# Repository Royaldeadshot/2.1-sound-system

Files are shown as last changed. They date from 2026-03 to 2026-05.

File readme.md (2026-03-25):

# DIY 3-Way Speaker Crossover + Amplifier System

This project is a custom-built 3-way audio system designed from scratch, including the amplifier, crossover network, and speaker configuration. The goal was to create a solid, practical setup that delivers good sound without overcomplicating the design.

---

## 🔊 System Overview

- Subwoofer: 10" DVC (handles low frequencies)
- Tower Speakers (x2):
  - 2 × Woofers (connected in series → 8Ω)
  - 1 × Midrange driver (4Ω)
  - 1 × Tweeter (4Ω)

- Passive 3-way crossover (2nd order)
- Custom PCB amplifier
  - Dual TPA3255 based amplifier

---

## 📸 Screenshots

### Full Build
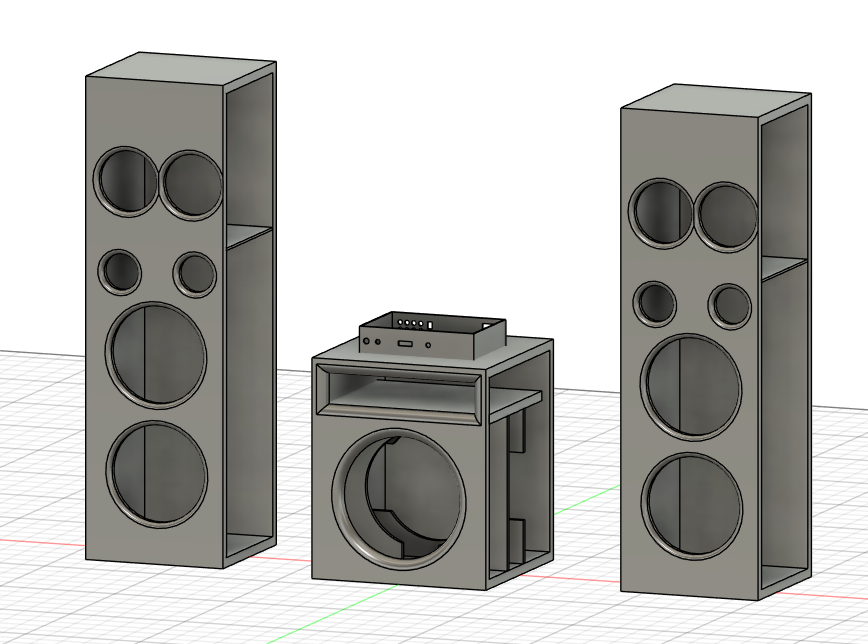
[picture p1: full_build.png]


### PCB Layout
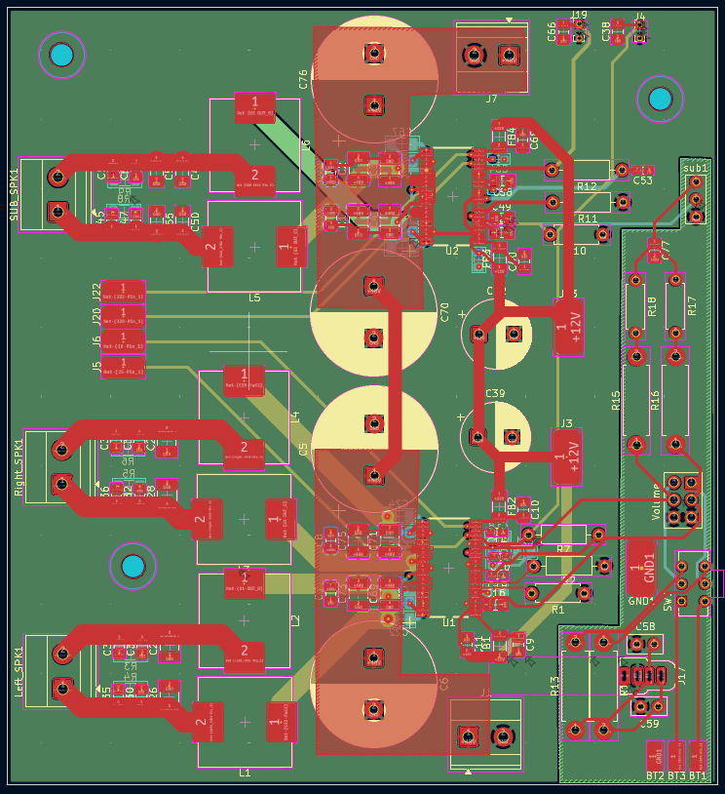
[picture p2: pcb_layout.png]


---

### Schematic
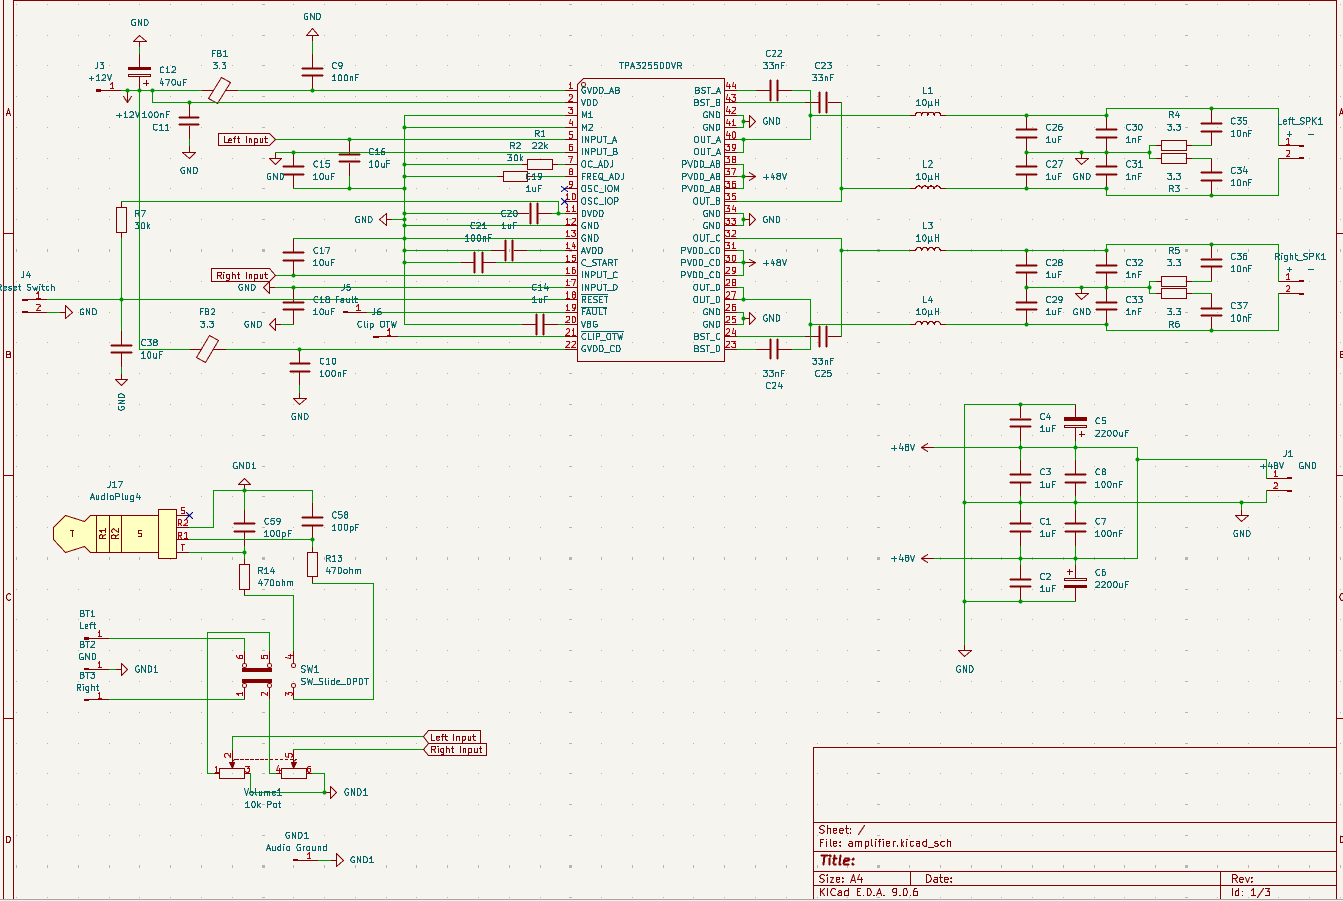
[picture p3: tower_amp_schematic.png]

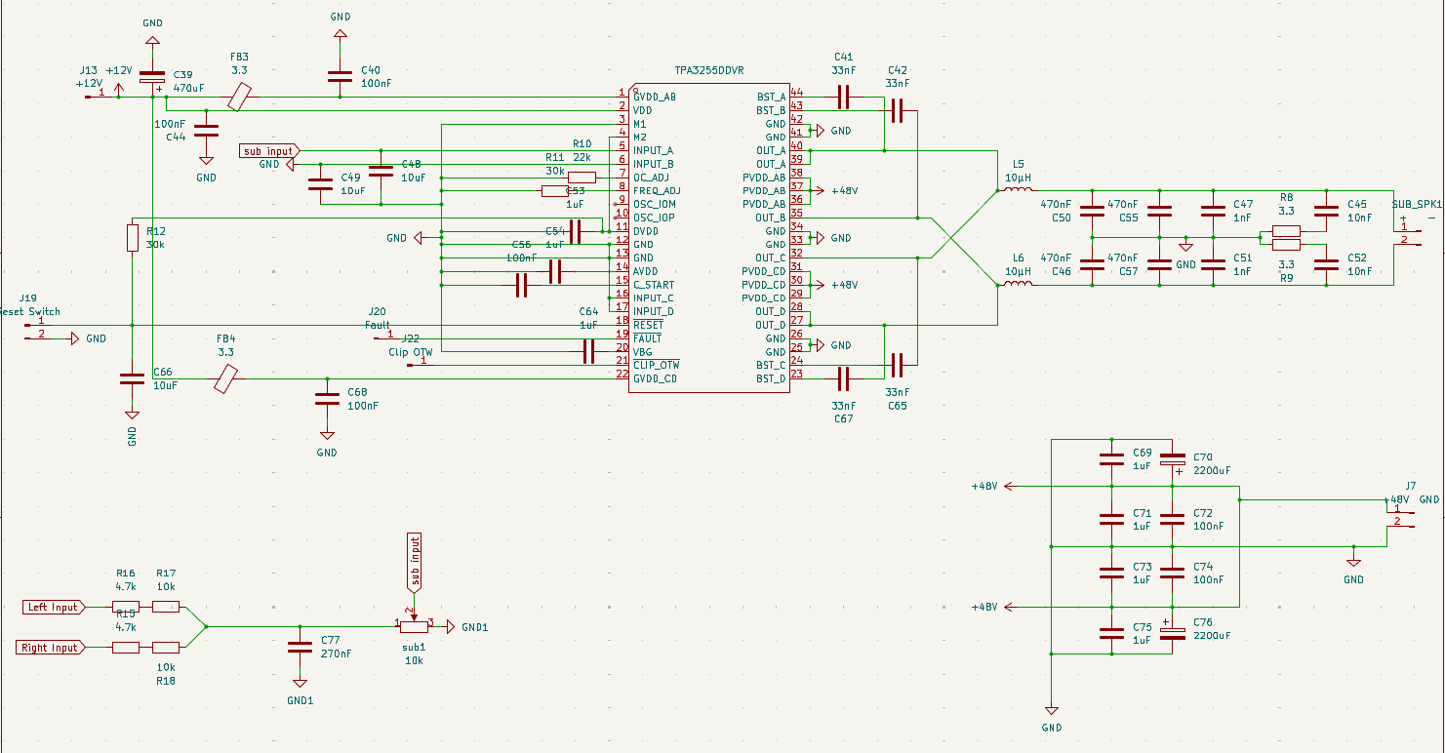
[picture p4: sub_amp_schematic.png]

---

### 3D Model
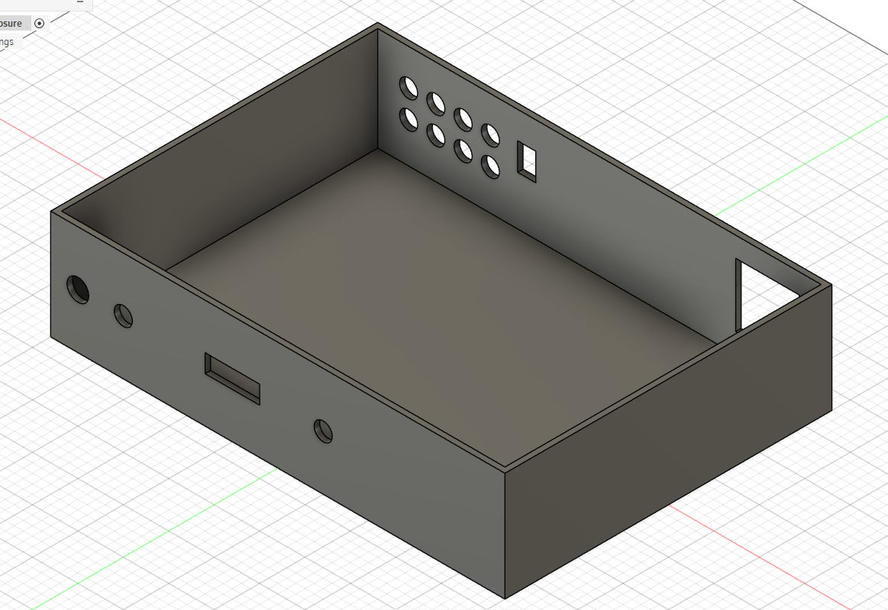
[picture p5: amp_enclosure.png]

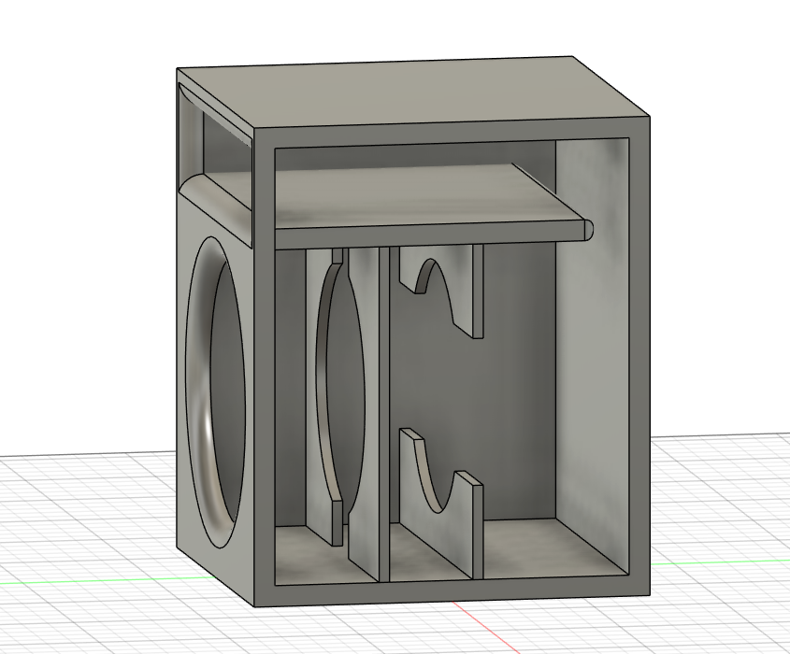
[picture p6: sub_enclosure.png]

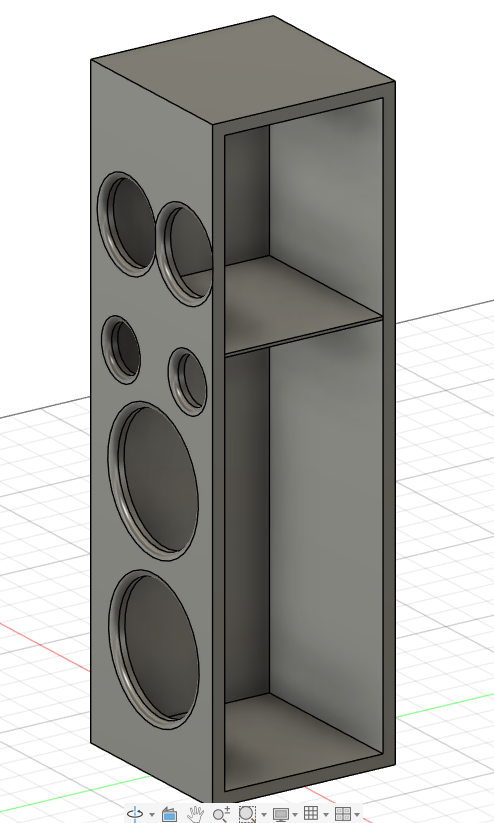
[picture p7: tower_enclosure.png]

---

### Crossover Design
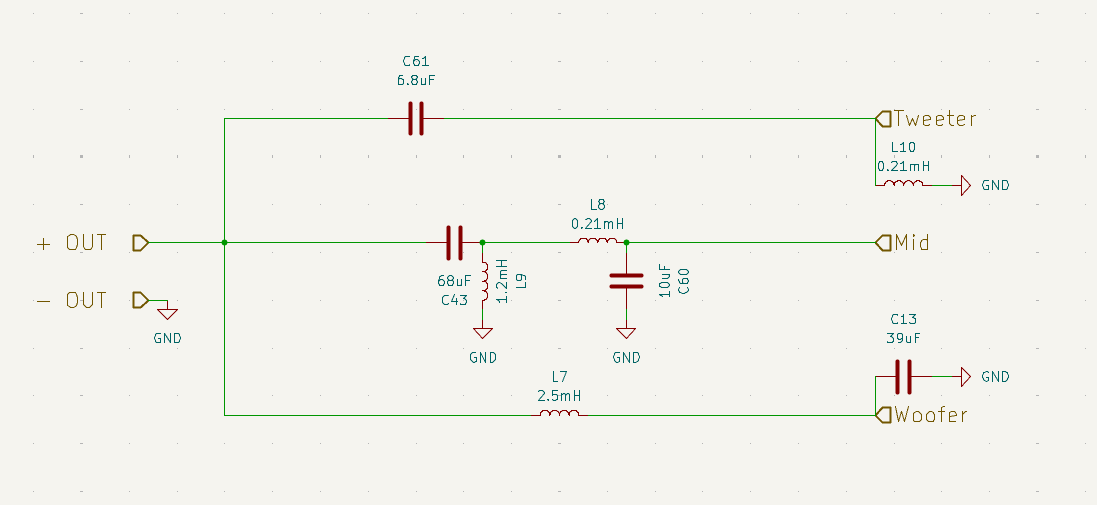
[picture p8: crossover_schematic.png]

---

## ⚙️ How It Works (Short)

The Power supply power up the sytem and then 48V and 12V are sent to amp power pins, and then 12v is also used to power up the fans for cooling the HOT TPA3255 chips, then the 5v is sent to bt module

after that we select aux or bt input through the dpdt switch, and the signal goes to the tower amp and a 80hz cutoff is sent to the sub amp, the amp amplify the dignal and then the amplifier sends a full-range audio signal to the crossover in tower speaker and the cutoff freq to sub.

The crossover splits this signal into three parts:

- Low frequencies → go to the woofers  
- Mid frequencies → go to the mid driver  
- High frequencies → go to the tweeter  

This is done using inductors and capacitors arranged as filters:

- Inductors block high frequencies  
- Capacitors block low frequencies  

Each driver only receives the frequencies it is meant to play, improving clarity and reducing distortion.

---

## 🧠 Design Choices

- TPA3255 for 250 watt per channel and 300-600 Watt for sub
- Used a 2nd order crossover (12dB/octave) for better separation   
- used a active crossover for sub to save cost

---

## 🧾 Components Used

BOM list present in the bom.csv in this repo root directory

---

## 🚀 Status

- [x] Amplifier designed  
- [x] PCB layout completed  
- [x] Crossover designed
- [X] Input Stage made
- [X] SUB frequecny cutoff of 80hz made
- [X] Tuned Enclosure design made
- [X] Drivers selected
- [X] BOM made
- [ ] Assembly  
- [ ] Testing  

---

## 📌 Future Improvements

- Fine-tune crossover after listening tests  
- Improve enclosure design  
- Add damping and internal bracing  

---

This is a work-in-progress build focused on learning and practical implementation rather than perfection.

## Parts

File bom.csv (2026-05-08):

S. No. | PCB Annotations | Part Name | Qty. | Unit Price(?) | Total Price(?) | Product link | Total Cost in $
1 | U1,U2 | TPA3255DDVR | 2 | 396 | 807 | https://www.lcsc.com/product-detail/C468240.html?s_z=n_tpa3255 | 8.54
2 | L1-L6 | 10uH Inductor | 7 | 32.5 | 276.6 | https://www.lcsc.com/product-detail/C5349630.html | 2.92
3 | SW1 | DPDT switch | 1 | 4.57 | 4.57 | https://robu.in/product/sk-3245d-02-l4-xkb-50ma-dpdt-12v-12v-50ma-10000-times-black-plugin-slide-switches-rohs/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 | 0.04
4 | J17 | aux input jack | 1 | 2.75 | 2.75 | https://robu.in/product/smartelex-audio-jack-3-5mm-trrs-smd/ | 0.02
5 | C77 | 270nF Ceramic Capacitor X7R 50V | 2 | 0.6 | 1.2 | https://robu.in/product/tcc0805x7r274k500dt-cctc-smt-ceramic-capacitors-0805-x7r-274k270nf%c2%b110-rated-voltage50v-thickness0-85mmtape/ | 0.01
6 | C59,C58 | 100pF ceramic capacitor 50V | 3 | 0.71 | 2.13 | https://robu.in/product/100pf-50v-ceramic-capacitordip-pack-of-50/ | 0.02
7 | R13,R14 | 470ohm resistor | 3 | 1 | 3 | https://robu.in/product/470-ohm-0-5w-metal-film-resistor-pack-of-50/ | 0.03
8 | J18 | Bluetooth Module | 1 | 300 | 300 | https://robocraze.com/products/dfrobot-bluetooth-5-0-audio-receiver-board?_pos=2&_sid=4add056a5&_ss=r | 3.17
9 | SUB1 | 10k Potentiometer A taper | 1 | 18 | 18 | https://makerbazar.in/products/wh148-3pin-20mm-rotary-shaft-potentiometer-audio-logarithm-a-taper-pots | 0.19
10 | VOLUME1 | 10k Potentiometer Dual gang | 1 | 22 | 22 | https://robu.in/product/10k%cf%89-0-2w-6-pin-2-gang-rotary-carbon-potentiometer-15mm/ | 0.23
11 | R15,R16 | 4.7k ohm metal film resistor | 3 | 0.7 | 2.1 | https://robu.in/product/4-7k-ohm-0-5w-metal-film-resistor-pack-of-50/ | 0.02
12 | R17,R18 | 10k ohm metal film resistor | 3 | 0.35 | 1.05 | https://robu.in/product/10k-ohm-0-25w-metal-film-resistor-pack-of-100/ | 0.01
13 | C1-4,C26-29,C69,C71,C73,C75 | 1uF Capacitor 100V ceramic | 15 | 9 | 135 | https://robu.in/product/cl32b105kcjnnne-samsang-100v-1uf-x7r-%c2%b110-1210-multilayer-ceramic-capacitors-mlcc-smd-smt-rohs/ | 1.43
14 | C53,C54,C64,C19,C20,C14 | 1uF Capacitor 25V ceramic | 8 | 1.61 | 12.88 | https://robu.in/product/tmk107b7105ka-t-taiyo-yuden-mlcc-capacitor-1uf-25v-x7r-10-0603/ | 0.14
15 | C5-6,C70,C76 | 2200uF electrolytic capacitor 63V | 5 | 141 | 705 | https://robu.in/product/upw1j222mhd-nichicon-2200uf-63v-%c2%b120-plugind18xl40mm-aluminum-electrolytic-capacitors-leaded-rohs/ | 7.46
16 | C40,C44,C68,C56,C72,C74,C9-11,C21,C7-8 | 100nF ceramic capacitor | 15 | 2.44 | 36.6 | https://robu.in/product/gcj21br72a104ka01l-murata-electronics-100v-100nf-x7r-%c2%b110-0805-multilayer-ceramic-capacitors-mlcc-smd-smt-rohs/ | 0.38
17 | C12,C39 | 470uF Electrolytic capacitor 50V | 3 | 7 | 21 | https://robu.in/product/470uf-50v-through-hole-1020-electrolytic-capacitor-pack-of-250/ | 0.22
18 | C15-18,C38,C48,C49,C66 | 10uF Ceramic Capacitor | 10 | 3.17 | 31.7 | https://robu.in/product/10uf-10000nf-25-v-capacitor-0805-smd-package-pack-of-10/ | 0.33
19 | C22-25,C41,C42,C65,C67 | 33nF 100V Ceramic Capacitor X7R | 10 | 0.79 | 7.9 | https://robu.in/product/tcc1206x7r333k101dt-cctc-smt-ceramic-capacitors-1206-x7r-333k33nf%c2%b110-rated-voltage100v-thickness0-85mm-tape/ | 0.08
20 | R1,R10 | 22k Ohm 0.25W Metal Film Resistor | 4 | 0.25 | 1 | https://robu.in/product/22k-ohm-0-25w-metal-film-resistor-pack-of-100/ | 0.01
21 | R2,R7,R11,R12 | 30k Ohm metal film Resistor | 5 | 2.18 | 10.9 | https://robu.in/product/mf25-30k-multicomp-pro-through-hole-resistor-30-kohm-mf25-series-250-mw-%c2%b1-1-axial-leaded-250-v/ | 0.11
22 | FB1-4, R3-R6,R8,R9 | 3.3Ohm Thick Filmc Resistor SMD | 15 | 0.26 | 3.9 | https://robu.in/product/1206w4f330kt5e-uniohm-royal-ohm-250mw-thick-film-resistors-200v-%c2%b11-%c2%b1400ppm-%e2%84%83-3-3%cf%89-1206-chip-resistor-surface-mo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 | 0.04
23 | C30-C33, C47, C51 | 1nF Capacitor 100V | 10 | 1.01 | 10.1 | https://robu.in/product/cc0805krx7r0bb102-yageo-100v-1nf-x7r-%c2%b110-0805-multilayer-ceramic-capacitors-mlcc-smd-smt-rohs/ | 0.1
24 | C34-C37, C45, C52 | 10nF Capacitor 100V | 10 | 1.79 | 17.9 | https://robu.in/product/gcm21br72a103ka37l-murata-electronics-100v-10nf-x7r-%c2%b110-0805-multilayer-ceramic-capacitors-mlcc-smd-smt-rohs/ | 0.18
25 | C46, C50, C55, C57 | 470nF Capacitor 100V | 6 | 1.73 | 10.38 | https://robu.in/product/1206b474k101nt-fh-100v-470nf-x7r%c2%b110-1206-multilayer-ceramic-capacitors-mlcc-smd-smt-rohs/ | 0.11
26 |  | Screw Terminal | 8 | 13 | 104 | https://robu.in/product/xy104-5-0-xinya-2-pin-screw-terminal-blockblue/ | 1.1
27 |  | 4mm Banana Plug Socket | 8 | 13 | 104 | https://robu.in/product/4mm-banana-socket-binding-post-nut-banana-plug-jack-connector/ | 1.1
28 |  | 48V To 12V Converter | 1 | 128 | 128 | https://robu.in/product/dc13-100v-to-12v-2a-buck-power-conversion-module/ | 1.35
29 |  | 40mm Fan | 2 | 65 | 130 | https://makerbazar.in/products/generic-axial-dc-cooling-fan-blowers?variant=46306240004336 | 1.37
30 |  | Aluminium Heat Sink 9 x 9 x 12 mm | 4 | 29 | 116 | https://robocraze.com/products/aluminum-cooling-heat-sink-chip-ram-radiator-heatsink-cooler-reprap-stepstick-heat-sink-9x9x12mm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 | 1.22
31 |  | 12V to 5V Converter | 1 | 166 | 166 | https://robu.in/product/24v-12v-to-5v-5a-power-module-dc-dc-xy-3606-power-converter/ | 1.75
32 |  | Heat Shrink Sleeve 8mm | 2 | 9 | 18 | https://robu.in/product/heat-shrink-sleeve-8mm-black-industrial-grade-woer-hst/ | 0.19
33 |  | 48V Power Supply 1000 Watts | 1 | 6999 | 6999 | https://www.amazon.in/Switching-Universal-Regulated-Transformer-1000Watts/dp/B0DNZJBZRN | 74.08
34 |  | 39uF Capacitor for Crossover | 2 | 13 | 26 | https://robu.in/product/100yxg39mefc8x16-rubycon-39uf-100v-%c2%b120-plugind8xl16mm-aluminum-electrolytic-capacitors-leaded-rohs/ | 0.27
35 |  | 68uF Capacitor for Crossover | 2 | 18 | 36 | https://robu.in/product/uhe2a680mpd1td-nichicon-68uf-%c2%b120-plugind10xl16mm-aluminum-electrolytic-capacitors-leaded-rohs/ | 0.38
36 |  | 2.5mH 16 AWG Steel Laminate Inductors | 2 | 700 | 1400 | https://audiofy.in/collections/air-core-coils/products/audiofy-2-5mh-16-awg-steel-laminate-inductors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 | 14.81
37 |  | 1.2mH 16 AWG Air Core Crossover Inductor | 2 | 960 | 1920 | https://audiofy.in/collections/air-core-coils/products/audiofy-1-2mh-16-awg-air-core-crossover-inductor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 | 20.32
38 |  | 0.21mH 16 AWG Air Core Crossover Inductor | 4 | 400 | 1600 | https://audiofy.in/products/audiofy-0-21mh-16-awg-air-core-crossover-inductor?_pos=3&_fid=0ef5b0c1e&_ss=c | 16.93
39 |  | 6.8uF 400VDC Metalized Polypropylene Capacitor | 2 | 190 | 380 | https://audiofy.in/collections/capacitors/products/audiofy-6-8uf-400vdc-metalized-polypropylene-capacitor | 4.02
40 |  | 10uF 400VDC Metalized Polypropylene Capacitor | 2 | 250 | 500 | https://audiofy.in/collections/capacitors/products/audiofy-10uf-400vdc-metalized-polypropylene-capacitor | 5.29
 |  | 16AWG black wire | 4 | 48 | 192 | https://robu.in/product/16awg-high-voltage-silicone-wire-3000v-black/ | 2.03
 |  | 16AWG red wire | 4 | 48 | 192 | https://robu.in/product/16awg-high-voltage-silicone-wire-3000v-red/ | 2.03
 |  | Multicore wire 14AWG | 2 | 202 | 404 | https://robu.in/product/14awg-multicore-insulated-cable2-cores-silicone/ | 4.28
 |  | 24AWG wire black | 1 | 12 | 12 | https://robu.in/product/24awg-high-voltage-silicone-wire-3000v-black/ | 0.12
 |  | 24AWG wire red | 1 | 12 | 12 | https://robu.in/product/24awg-high-voltage-silicone-wire-3000v-red/ | 0.12

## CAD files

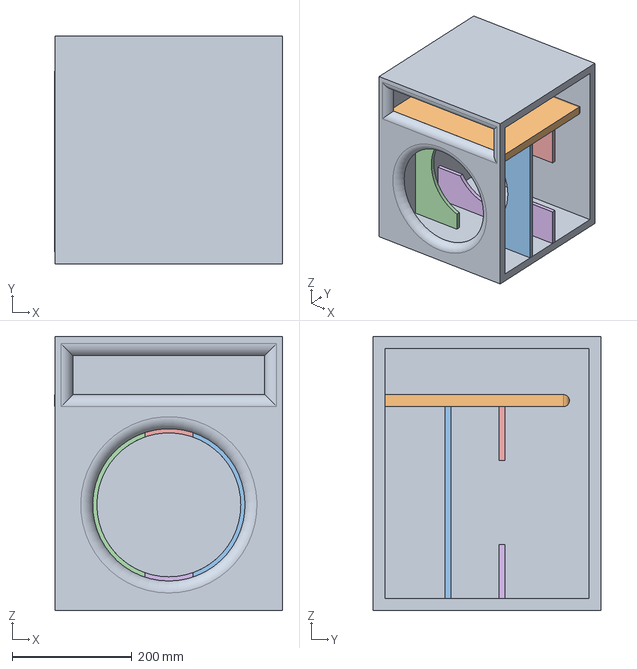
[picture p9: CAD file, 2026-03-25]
CAD/Sub Woofer Enclosure.step
381.0 x 380.0 x 457.0 mm

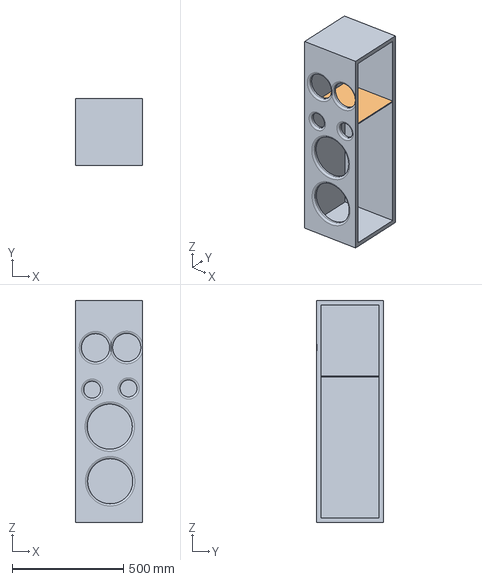
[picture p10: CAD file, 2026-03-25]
CAD/Tower Design.step
300.0 x 300.0 x 1000.0 mm

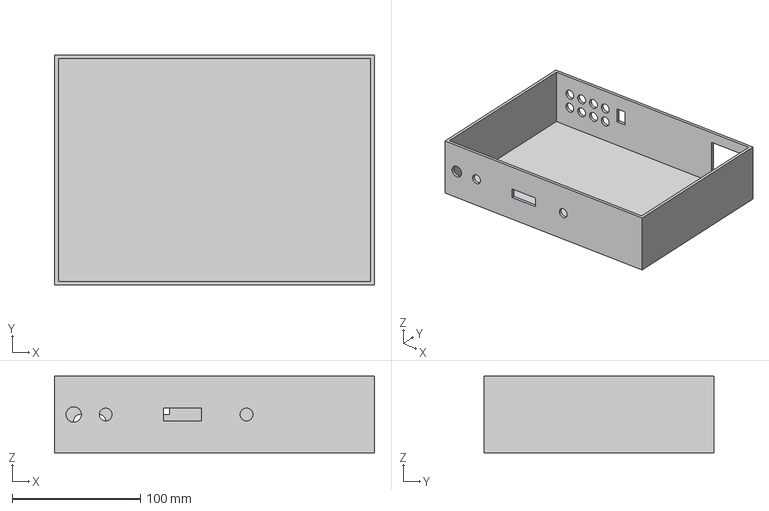
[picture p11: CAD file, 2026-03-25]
CAD/Amplifier Enclosure.step
250.0 x 180.0 x 60.0 mm

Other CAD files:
CAD/Amplifier Enclosure.f3d
CAD/Sub Woofer Enclosure.f3d
CAD/Tower Design.f3d

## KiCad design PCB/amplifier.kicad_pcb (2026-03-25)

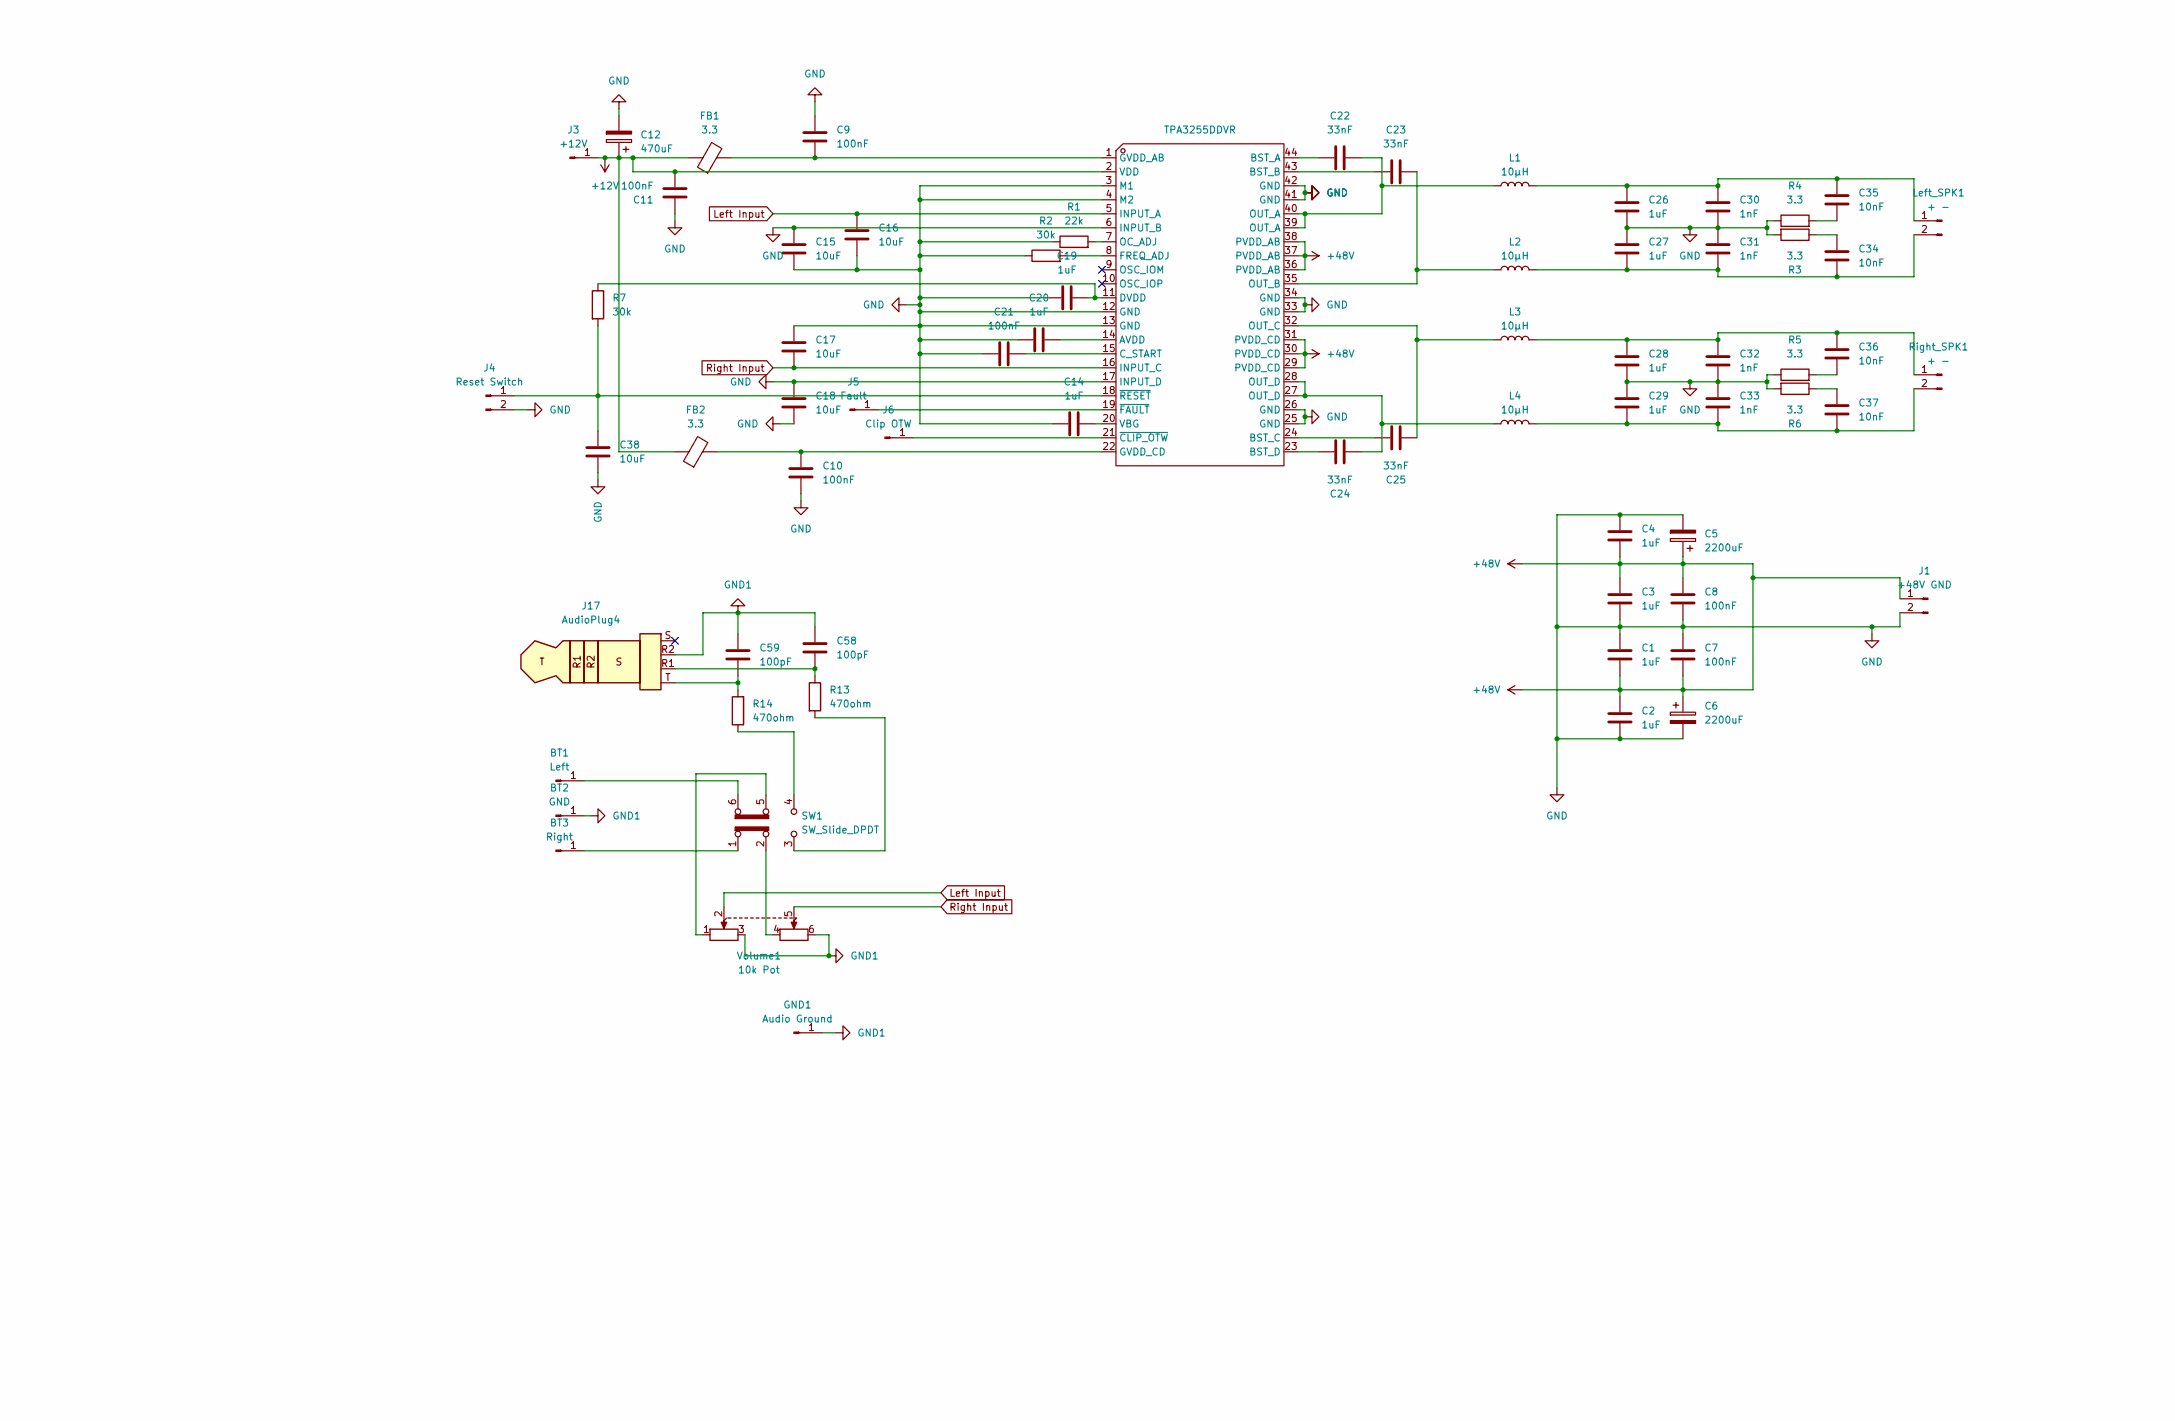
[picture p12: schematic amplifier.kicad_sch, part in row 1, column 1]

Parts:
BT1: Left; SolderWirePad_1x01_SMD_2x4mm
BT2: GND; SolderWirePad_1x01_SMD_2x4mm
BT3: Right; SolderWirePad_1x01_SMD_2x4mm
C1, C2, C3, C4, C26, C27, C28, C29: 1uF; C_1210_3225Metric_Pad1.33x2.70mm_HandSolder
C5, C6: 2200uF; CP_Radial_D18.0mm_P7.50mm
C7, C8, C9, C10, C11, C21: 100nF; C_0805_2012Metric_Pad1.18x1.45mm_HandSolder
C12: 470uF; CP_Radial_D10.0mm_P5.00mm
C14, C19, C20: 1uF; C_0603_1608Metric_Pad1.08x0.95mm_HandSolder
C15, C16, C17, C18, C38: 10uF; C_0805_2012Metric_Pad1.18x1.45mm_HandSolder
C22, C23, C24, C25: 33nF; C_1206_3216Metric_Pad1.33x1.80mm_HandSolder
C30, C31, C32, C33: 1nF; C_0805_2012Metric_Pad1.18x1.45mm_HandSolder
C34, C35, C36, C37: 10nF; C_0805_2012Metric_Pad1.18x1.45mm_HandSolder
C58, C59: 100pF; C_Disc_D5.0mm_W2.5mm_P2.50mm
FB1, FB2: 3.3; R_1206_3216Metric_Pad1.30x1.75mm_HandSolder
GND1: Audio Ground; SolderWirePad_1x01_SMD_4x8mm
J1: +48V GND; TerminalBlock_Phoenix_MKDS-1,5-2_1x02_P5.00mm_Horizontal
J3: +12V; SolderWirePad_1x01_SMD_4x8mm
J4: Reset Switch; PinHeader_1x02_P1.00mm_Vertical
J5: Fault; SolderWirePad_1x01_SMD_3x6mm
J6: Clip OTW; SolderWirePad_1x01_SMD_3x6mm
J17: AudioPlug4; Plug_3.5mm_CUI_SP-3541
L1, L2, L3, L4: 10µH; L_APV_APH1265
Left_SPK1: + -; TerminalBlock_Phoenix_MKDS-1,5-2_1x02_P5.00mm_Horizontal
R1: 22k; R_Axial_DIN0207_L6.3mm_D2.5mm_P7.62mm_Horizontal
R2, R7: 30k; R_Axial_DIN0207_L6.3mm_D2.5mm_P10.16mm_Horizontal
R3, R4, R5, R6: 3.3; R_1206_3216Metric_Pad1.30x1.75mm_HandSolder
R13, R14: 470ohm; R_Axial_DIN0411_L9.9mm_D3.6mm_P12.70mm_Horizontal
Right_SPK1: + -; TerminalBlock_Phoenix_MKDS-1,5-2_1x02_P5.00mm_Horizontal
SW1: SW_Slide_DPDT; SW_CK_JS202011AQN_DPDT_Angled
U1: TPA3255DDVR; HTSSOP-44_L14.0-W6.1-P0.64-LS8.1-BL; LCSC Part C468240
Volume1: 10k Pot; Potentiometer_Alpha_RD902F-40-00D_Dual_Vertical

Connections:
+12V: C11.2, C12.1, FB1.1, FB2.1, J3.1, U1.2 (VDD); also elsewhere on the board
+48V: C1.2, C2.1, C3.1, C4.2, C5.1, C6.1, C7.2, C8.1, J1.1, U1.29 (PVDD_CD), U1.30 (PVDD_CD), U1.31 (PVDD_CD), U1.36 (PVDD_AB), U1.37 (PVDD_AB), U1.38 (PVDD_AB); also elsewhere on the board
GND: C1.1, C2.2, C3.2, C4.1, C5.2, C6.2, C7.1, C8.2, C9.2, C10.1, C11.1, C12.2, C14.2, C15.1, C15.2, C16.2, C17.1, C18.1, C18.2, C19.1, C20.1, C21.1, C26.2, C27.1, C28.2, C29.1, C30.2, C31.1, C32.2, C33.1, C38.1, J1.2, J4.2, R1.1, R2.1, R3.2, R4.1, R5.1, R6.2, U1.3 (M1), U1.4 (M2), U1.6 (INPUT_B), U1.12 (GND), U1.13 (GND), U1.17 (INPUT_D), U1.25 (GND), U1.26 (GND), U1.33 (GND), U1.34 (GND), U1.41 (GND), U1.42 (GND); also elsewhere on the board
GND1: BT2.1, C58.1, C59.2, GND1.1, J17.R2, Volume1.3, Volume1.6; also elsewhere on the board
Left Input: C16.1, U1.5 (INPUT_A), Volume1.2; also elsewhere on the board
unnamed: BT1.1, SW1.6 (C)
unnamed: BT3.1, SW1.1 (A)
unnamed: C22.2, L1.1, U1.39 (OUT_A), U1.40 (OUT_A)
unnamed: C24.1, L4.1, U1.27 (OUT_D), U1.28 (OUT_D)
unnamed: C34.1, R3.1
unnamed: C35.2, R4.2
unnamed: C36.2, R5.2
unnamed: C37.1, R6.1
unnamed: C58.2, J17.R1, R13.1
unnamed: C59.1, J17.T, R14.2
unnamed: C38.2, J4.1, R7.2, U1.18 (~RESET)
unnamed: J5.1, U1.19 (~FAULT)
unnamed: J6.1, U1.21 (~CLIP_OTW)
unnamed: C26.1, C30.1, C35.1, L1.2, Left_SPK1.1
unnamed: C27.2, C31.2, C34.2, L2.2, Left_SPK1.2
unnamed: R13.2, SW1.3 (C)
unnamed: R14.1, SW1.4 (A)
unnamed: C28.1, C32.1, C36.1, L3.2, Right_SPK1.1
unnamed: C29.2, C33.2, C37.2, L4.2, Right_SPK1.2
unnamed: SW1.2 (B), Volume1.4
unnamed: SW1.5 (B), Volume1.1
unnamed: C20.2, U1.14 (AVDD)
unnamed: C22.1, U1.44 (BST_A)
unnamed: C23.1, U1.43 (BST_B)
unnamed: C25.2, U1.24 (BST_C)
unnamed: C24.2, U1.23 (BST_D)
unnamed: C21.2, U1.15 (C_START)
unnamed: C19.2, R7.1, U1.11 (DVDD)
unnamed: R2.2, U1.8 (FREQ_ADJ)
unnamed: C9.1, FB1.2, U1.1 (GVDD_AB)
unnamed: C10.2, FB2.2, U1.22 (GVDD_CD)
unnamed: R1.2, U1.7 (OC_ADJ)
unnamed: C23.2, L2.1, U1.35 (OUT_B)
unnamed: C25.1, L3.1, U1.32 (OUT_C)
unnamed: C14.1, U1.20 (VBG)
Right Input: C17.2, U1.16 (INPUT_C), Volume1.5; also elsewhere on the board

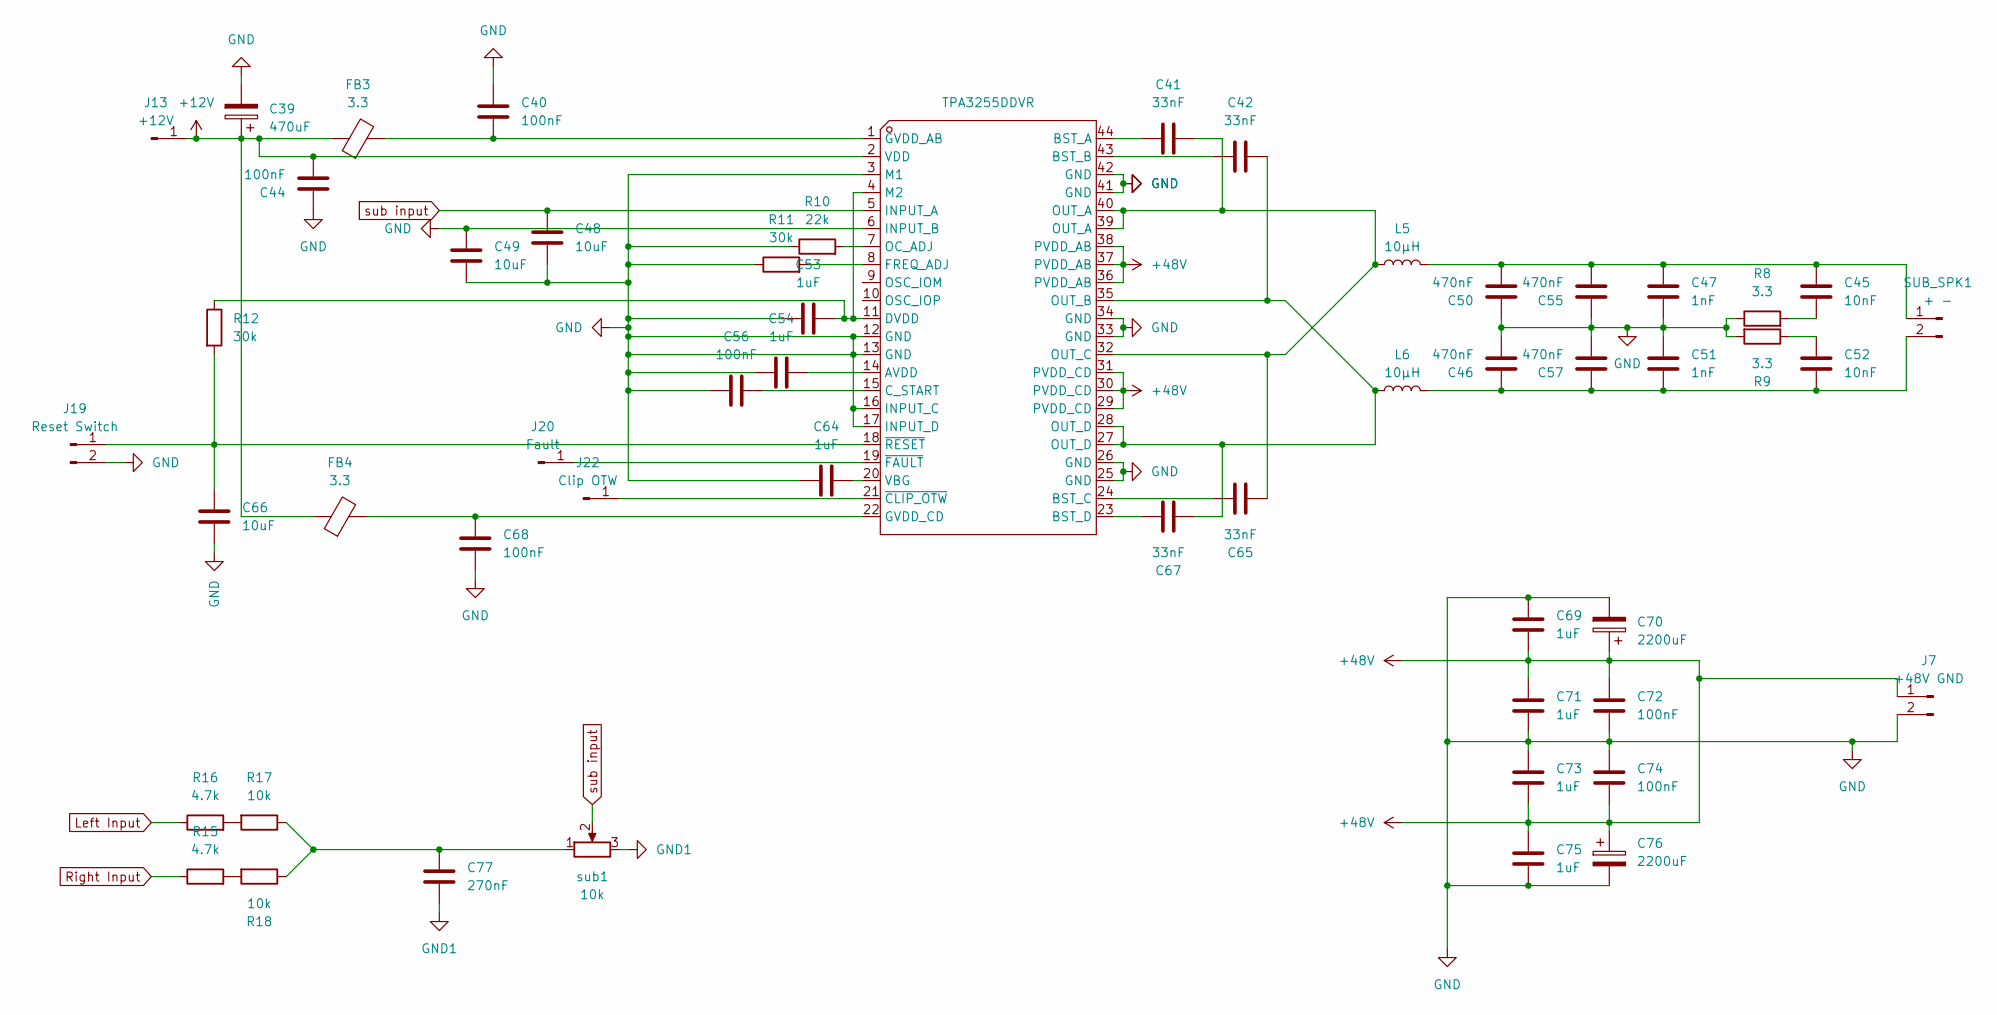
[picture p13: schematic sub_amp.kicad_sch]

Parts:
C39: 470uF; CP_Radial_D10.0mm_P5.00mm
C40, C44, C56, C68, C72, C74: 100nF; C_0805_2012Metric_Pad1.18x1.45mm_HandSolder
C41, C42, C65, C67: 33nF; C_1206_3216Metric_Pad1.33x1.80mm_HandSolder
C45, C52: 10nF; C_0805_2012Metric_Pad1.18x1.45mm_HandSolder
C46, C50, C55, C57: 470nF; C_1206_3216Metric_Pad1.33x1.80mm_HandSolder
C47, C51: 1nF; C_0805_2012Metric_Pad1.18x1.45mm_HandSolder
C48, C49, C66: 10uF; C_0805_2012Metric_Pad1.18x1.45mm_HandSolder
C53, C54, C64: 1uF; C_0603_1608Metric_Pad1.08x0.95mm_HandSolder
C69, C71, C73, C75: 1uF; C_1210_3225Metric_Pad1.33x2.70mm_HandSolder
C70, C76: 2200uF; CP_Radial_D18.0mm_P7.50mm
C77: 270nF; C_0805_2012Metric_Pad1.18x1.45mm_HandSolder
FB3, FB4: 3.3; R_1206_3216Metric_Pad1.30x1.75mm_HandSolder
J7: +48V GND; TerminalBlock_Phoenix_MKDS-1,5-2_1x02_P5.00mm_Horizontal
J13: +12V; SolderWirePad_1x01_SMD_4x8mm
J19: Reset Switch; PinHeader_1x02_P1.00mm_Vertical
J20: Fault; SolderWirePad_1x01_SMD_3x6mm
J22: Clip OTW; SolderWirePad_1x01_SMD_3x6mm
L5, L6: 10µH; L_APV_APH1265
R8, R9: 3.3; R_1206_3216Metric_Pad1.30x1.75mm_HandSolder
R10: 22k; R_Axial_DIN0207_L6.3mm_D2.5mm_P7.62mm_Horizontal
R11, R12: 30k; R_Axial_DIN0207_L6.3mm_D2.5mm_P10.16mm_Horizontal
R15, R16: 4.7k; R_Axial_DIN0411_L9.9mm_D3.6mm_P12.70mm_Horizontal
R17, R18: 10k; R_Axial_DIN0207_L6.3mm_D2.5mm_P7.62mm_Horizontal
SUB_SPK1: + -; TerminalBlock_Phoenix_MKDS-1,5-2_1x02_P5.00mm_Horizontal
U2: TPA3255DDVR; HTSSOP-44_L14.0-W6.1-P0.64-LS8.1-BL; LCSC Part C468240
sub1: 10k; Potentiometer_ACP_CA6-H2,5_Horizontal

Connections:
+12V: C39.1, C44.2, FB3.1, FB4.1, J13.1, U2.2 (VDD); also elsewhere on the board
+48V: C69.2, C70.1, C71.1, C72.1, C73.2, C74.2, C75.1, C76.1, J7.1, U2.29 (PVDD_CD), U2.30 (PVDD_CD), U2.31 (PVDD_CD), U2.36 (PVDD_AB), U2.37 (PVDD_AB), U2.38 (PVDD_AB); also elsewhere on the board
GND: C39.2, C40.2, C44.1, C46.2, C47.2, C48.2, C49.1, C49.2, C50.1, C51.1, C53.1, C54.1, C55.1, C56.1, C57.2, C64.2, C66.1, C68.1, C69.1, C70.2, C71.2, C72.2, C73.1, C74.1, C75.2, C76.2, J7.2, J19.2, R8.1, R9.2, R10.1, R11.1, U2.3 (M1), U2.6 (INPUT_B), U2.12 (GND), U2.13 (GND), U2.16 (INPUT_C), U2.17 (INPUT_D), U2.25 (GND), U2.26 (GND), U2.33 (GND), U2.34 (GND), U2.41 (GND), U2.42 (GND); also elsewhere on the board
GND1: C77.2, sub1.3; also elsewhere on the board
Left Input: R16.1; also elsewhere on the board
unnamed: C45.2, R8.2
unnamed: C52.1, R9.1
unnamed: C77.1, R17.1, R18.1, sub1.1
unnamed: C66.2, J19.1, R12.2, U2.18 (~RESET)
unnamed: J20.1, U2.19 (~FAULT)
unnamed: J22.1, U2.21 (~CLIP_OTW)
unnamed: R15.2, R18.2
unnamed: R16.2, R17.2
unnamed: C45.1, C47.1, C50.2, C55.2, L5.2, SUB_SPK1.1
unnamed: C46.1, C51.2, C52.2, C57.1, L6.2, SUB_SPK1.2
unnamed: C54.2, U2.14 (AVDD)
unnamed: C41.1, U2.44 (BST_A)
unnamed: C42.1, U2.43 (BST_B)
unnamed: C65.2, U2.24 (BST_C)
unnamed: C67.2, U2.23 (BST_D)
unnamed: C56.2, U2.15 (C_START)
unnamed: C53.2, R12.1, U2.4 (M2), U2.11 (DVDD)
unnamed: R11.2, U2.8 (FREQ_ADJ)
unnamed: C40.1, FB3.2, U2.1 (GVDD_AB)
unnamed: C68.2, FB4.2, U2.22 (GVDD_CD)
unnamed: R10.2, U2.7 (OC_ADJ)
unnamed: C42.2, C67.1, L6.1, U2.27 (OUT_D), U2.28 (OUT_D), U2.35 (OUT_B)
unnamed: C41.2, C65.1, L5.1, U2.32 (OUT_C), U2.39 (OUT_A), U2.40 (OUT_A)
unnamed: C64.1, U2.20 (VBG)
Right Input: R15.1; also elsewhere on the board
sub input: C48.1, U2.5 (INPUT_A), sub1.2

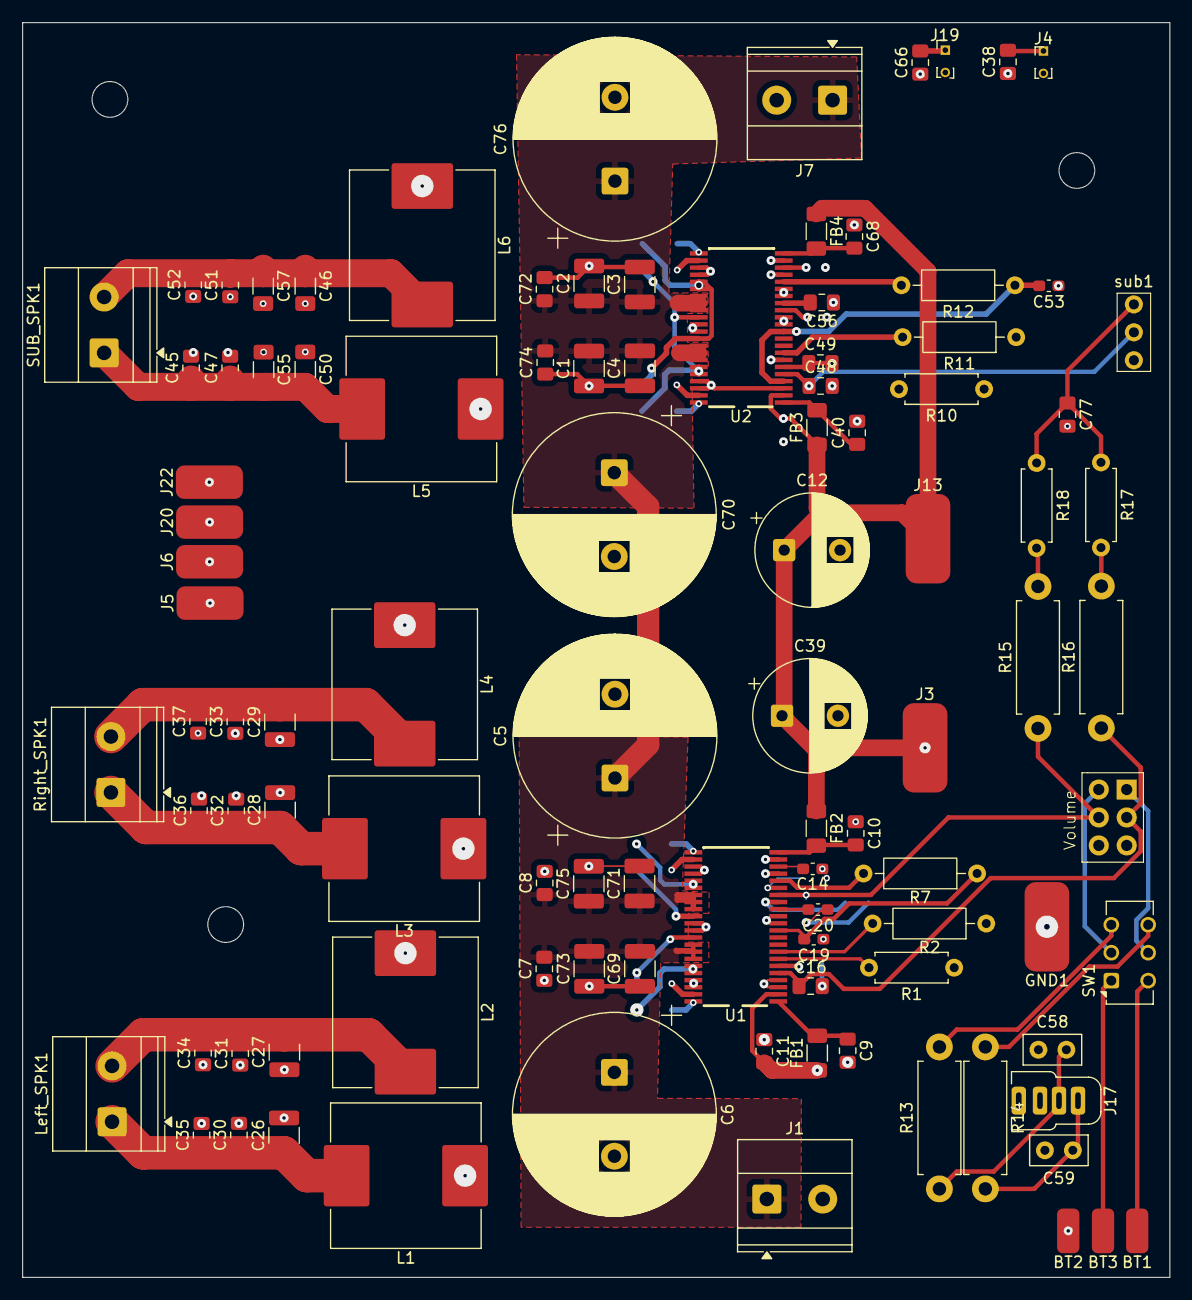
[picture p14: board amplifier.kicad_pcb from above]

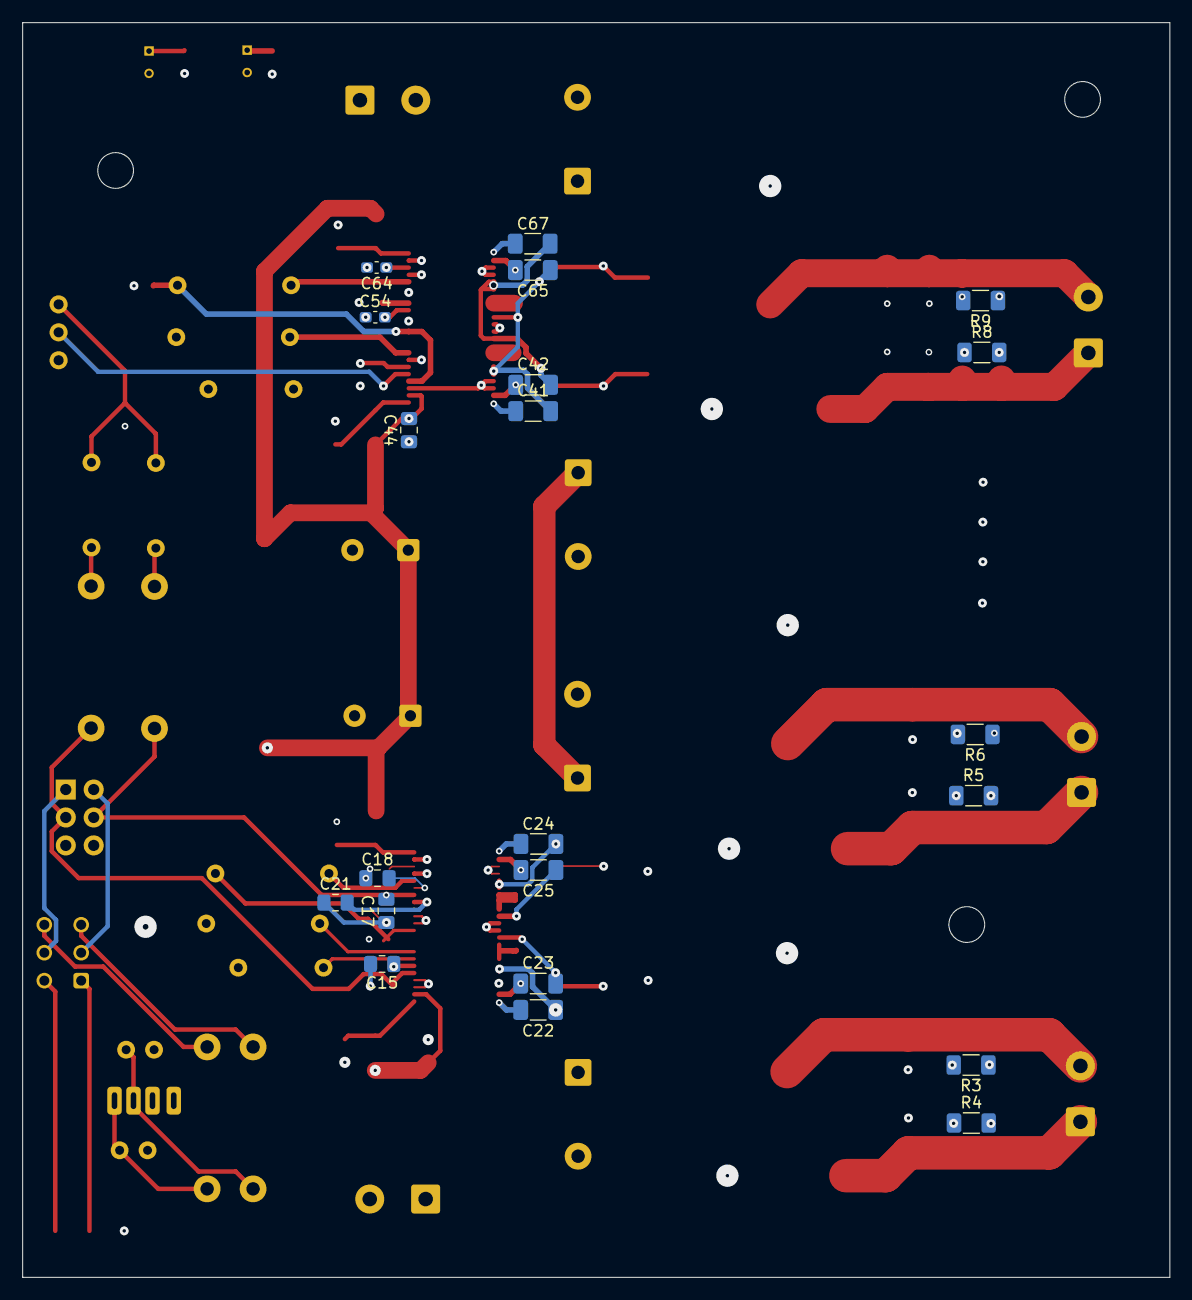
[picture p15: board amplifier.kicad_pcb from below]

Board: 4 copper layers, 102.7 x 112.3 mm, 122 parts (21 on the bottom side), 66 nets.
